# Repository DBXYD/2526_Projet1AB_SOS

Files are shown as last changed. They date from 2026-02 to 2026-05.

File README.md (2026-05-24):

# 2526_Projet1AB_SOS
## Introduction
### 1.1 Contexte et Problématique
Dans le cadre de la gestion logistique des laboratoires de l'ENSEA, le suivi précis et rigoureux des composants électroniques constitue un défi quotidien. Actuellement, l'inventaire repose sur un référencement manuel via un fichier Excel, et le stockage physique est réparti dans des boîtes de dimensions variables.
Ce mode de gestion présente plusieurs limites :

- Erreurs d'indexation : Risque élevé d'oublis ou de doubles saisies lors d'une mise à jour des stocks.
- Perte de traçabilité spatiale : Difficulté à localiser physiquement les boîtes suite à des déplacements ou réorganisations.
- Asynchronisme des données : Décalage temporel entre le mouvement réel d'un composant et sa mise à jour logicielle.

### 1.2 Objectifs du Projet SOS
Le projet SOS (Stock Organizer Scan) vise à concevoir un système embarqué de numérisation basé sur la technologie RFID (Radio Frequency Identification).
Chaque boîte de rangement se voit attribuer un tag RFID unique. Le dispositif SOS lit et écrit ces puces pour associer un contenant physique à ses données logistiques :
- Le MPN (Manufacturer Part Number) : référence exacte du constructeur
- SKU (Stock Keeping Unit) : code interne d'identification du stock
- LocalisationSalle précise au sein des différents tiroclasses de l'ENSEA
- Quantité exacte d'exemplaires restants

### 1.3 Solution mise en œuvre
Le projet s'articule autour de deux parties :

1) [Hardware](./Hardware) : Une carte électronique sur mesure intégrant une carte électronique sur mesure intégrant un microcontrôleur basse
consommation STM32L4, un lecteur RFID communiquant via bus SPI matériel, et une interface USB-C assurant à la fois l’alimentation et l’échange de données haut débit.

3) [Software](./Software) : Une interface utilisateur développée en Python, permettant aux techniciens d'interagir avec la base de données.

## 2. Analyse détaillée des blocs fonctionnels
Le schématique du système SOS (Stock Organizer Scan) est structuré de manière ri-
goureuse en blocs fonctionnels distincts.

### 2.1 Bloc Alimentation (Power Supply)



Ce bloc assure la conversion et la régulation de l'énergie nécessaire aux différents composants.

- Composants identifiés :
  - Régulateur LDO :  BU33SD5WG-TR (5 V → 3.3 V)
  - Condensateurs : C1 (1 μF) et C2 (1 μF)
  - Interrupteur : SW_SPDT (SW1)
  - LEDs indicatrices : D1 et D2 avec résistances associées R3 (3.4 kΩ) et R4 (1.6 kΩ)

- Justification des choix :
  - BU33SD5WG-TR : Ce régulateur (LDO) est particulièrement adapté pour abaisser le 5V issu de l’USB vers le rail 3.3 V. Son boîtier compact minimise l’empreinte au sol. De plus, sa capacité en courant ici est largement suffisante pour alimenter simultanément notre microcontrôleur STM32 et le lecteur RFID.

  - C1 et C2 (1 μF) : Placés en découplage direct sur l’entrée et la sortie du LDO conformément aux spécifications du constructeur. Ils stabilisent la tension ici.
  - SW1 (SW_SPDT) : Permet de couper l’alimentation de la carte sans avoir à débrancher physiquement le câble USB. Cela est plutôt intéressant d’un point de vue confort d’utilisation.

### 2.2 Bloc Port USB (USB-C)



L'interface USB-C gère le transfert de données et l'apport d'énergie principal.

- Composants identifiés :
  - Connecteur USB-C : J1 (Référence commerciale : 629722000214)
  - Protection ESD : U2 (USBLC6-2SC6)
  - Résistances de configuration : R1 (5.4 kΩ), R2 (5.1 kΩ) sur les lignes CC1/CC2
  - 
- Justification des choix :
  - Connecteur Molex USB-C : Nous avons opter ici pour USB-C et non un Micro-USB car
le premier est réversible et largement plus robustesse.
  - USBLC6-2SC6 : Réseau de diodes TVS bidirectionnel ultra-faible capacité dédié à la
protection des lignes D+ et D−. Cette protection est indispensable contre les décharges
électrostatiques (ESD) induites lorsque’un humaine manipule le connecteur USB manuellement.

### 2.3 Bloc STM32 (Microcontrôleur principal)



Le cœur logique du système repose sur le STM32L476RGTx (boîtier LQFP64) de STMicroelectronics. Composant central : STM32L476RGTx.

Ecosystème ENSEA : Il s’agit d’un composant sur lequel nous avons ulterieusrement eu a travaillé durant les séances de TD et TP surtout. SPI Matériel dispose de plusieurs bus SPI indépendants pour piloter à haute fréquence le lecteur RFID.

- Signaux notables :
  - SPI1_* → Liaison vers le lecteur RFID.
  - VCP_TX / VCP_RX → Interface UART pontée vers l’USB pour la communication avec le
script Python.
  - USB_DN / USB_DP → Lignes différentielles du bus USB physique.
  - SWDIO / SWCLK → Interface de programmation/débogage JTAG/SWD.
  - USR_LED_1 / USR_LED_2 → Indication d’état utilisateur (ex : scan réussi).
  - NRST / BOOT0 → Lignes de contrôle.
 
Remarque : Les condensateurs de découplage (C5 à C10, 100 nF) sont assignés individuellement à chaque broche d’alimentation VDD du STM32. Ils suppriment le bruit haute fréquence issu des commutations internes du coeur.

### 2.4 Bloc Lecteur RFID


Ce bloc gère l'acquisition des données des tags RFID attachés aux produits stockés.

- Interface SPI : Exploitation du bus à haute vitesse (jusqu’à 10 Mbit/s), réduisant la
latence lors de la lecture des identifiants.
- Compatibilité de tension : Fonctionnant sous 3.3 V, le composant fonctione directement
avec le STM32.
- Découplage local (C13,C14 - 1 μF) : Placés au plus près du circuit RFID pour pallier les
appels de courant violents générés par l’antenne lors de l’émission du champ magnétique
RF.

### 2.5 Bloc Connecteur SWD


Ce bloc offre un accès direct aux broches de débogage via une sonde externe de type ST-Link, pour le flashage et le débogage à chaud du microcontrôleur.

### 2.6 Boutons et signaux utilisateur





### 2.7 Trous de fixation (Mounting Pads)



Les quatre perçages H1 à H4 (MountingHole_Pad) garantissent la rigidité de l’intégration au sein d’un boîtier personnalisé.

## 3. Routage
Le passage du schéma théorique du [PCB](./PCB) permettant le tracé des pistes physiques impose le respect de contraintes géométriques et électromagnétiques strictes.



### 3.1 Réalisation Matérielle et Placements des blocs

La conception du circuit imprimé a abouti à une modélisation tridimensionnelle permettant de valider l’intégration mécanique des composants, l’accessibilité des connecteurs.

Le microcontrôleur STM32L476RGTx (boîtier LQFP64) occupe une position parfaitement centrale. Cette disposition permet une distribution homogène des pistes de signaux vers les différents périphériques, minimisant ainsi la longueur moyenne des pistes.

- Implantation des diffférents blocs :
  - Connecteur USB-C et Protection ESD : Placés au plus près du bord de la carte. L’alignement direct du circuit de protection TVS en entrée du connecteur garantit que les décharges électrostatiques sont immédiatement dérivées vers la masse avant de pouvoir se propager vers l’intérieur du circuit.
  - Connecteur d’extension RFID : Disposé sur la périphérie supérieure sous forme d’un connecteur femelle barrette, offrant une liaison mécanique et électrique stable pour le module MFRC522 tout en évitant les superpositions de composants.
  - Connecteur SWD (J2) : Isolé à droite afin de permettre un raccordement aisé de la sonde ST-Link lors des phases de flashage sans gêner l’accès au port USB principal.
  - Mounting Pads : la présence de quatre trous de fixation métallisés (Mounting Pads) répartis de manière symétrique aux quatre angles de la carte valide l’aptitude du prototype à être intégré de manière rigide au sein d’un boîtier de protection. L’espacement laissé libre autour de ces trous garantit le passage des têtes de vis sans risque d’écrasement ou de court-circuit sur les pistes environnantes.

## 4. Configuration des pins


Le microcontrôleur STM32L476RGTx (LQFP64) est configuré avec les affectations suivantes :



- Port A — SPI1 (NSS, SCK, MISO, MOSI), USB (DM, DP), VCP (TX, RX)
- Port B — RFID IRQ, boutons utilisateur (BTN_1, BTN_2), SWD, LEDs utilisateur
- Port C — OSC, LEDs, RFID RST
- Signaux de contrôle — NRST, BOOT0

## 5. Software
### 5.1 Firmware
La liaison entre le PC et le tag RFID à travers le PCB est gérée par du code en C, où on retrouve une séparation par composants. Le projet est construit de manière à pouvoir réutiliser des morceaux du code pour d’autres projets faisant intervenir des composants de celui-ci.\
Par la suite on détaillera seulement les fichiers contenant des fonctions écrites par nous, et non des fichiers générés par STM32CubeIDE lors de l'affectation des pins sur le .ioc (gpio, spi, usart,...).\

Dans le main.c se trouvent des appels aux fonctions d'initialisation et une boucle infinie où l'appel à test() de algo.c permet de tester des fonctionnalités en mode debuggeur.\
\
Le fichier rfid.c contient des fonctions ayant trait à la liaison SPI entre la STM32 et le lecteur RFID, et une structure permettant de définir les broches associées à un lecteur RFID. Cette dernière est initialisée grâce à la fonction RFID_init(hrfid, hspi, hspi_nss_port, hspi_nss_pin, rst_port, rst_pin). 

- void RFID_transmit(RFID_HandleTypeDef* hrfid, uint8_t* data, int size) transmet les données de data au tag et les y écrit;
- void RFID_receive(RFID_HandleTypeDef* hrfid, uint8_t* data, int size) lit les données du tag et les envoie au master en les stockant dans un buffer data.
- void RFID_transmit_receive(RFID_HandleTypeDef* hrfid, uint8_t* pTxData, uint8_t* pRxData, int size) fait les deux, l’un après l’autre.

Le fichier algo.c contient des fonctions rassemblant celles des autres fichiers, mettant ainsi bout à bout les différents éléments du PCB. Les fonctions read et write font alors intervenir le lecteur RFID et la liaison USART avec le PC. 

- void test() est utile pour la phase développement: elle aide à vérifier le fonctionnement de read(huart, hrfid, pdata, size) et write(huart, hrfid, pdata, size). On commence par lire le tag RFID, puis on y enregistre des données qu’on cherche enfin à retrouver en refaisant appel à read. 

- uint8_t SPI1_WriteRead(uint8_t data, SPI_HandleTypeDef hspi1) fait appel à RRFID_transmit_receive(hrfid, pTxData, pRxData, size). Elle est particulièrement utile dans les cas où ces deux actions doivent être effectuées l’une après l’autre. RFID_transmit_receive gère le délai de transmission. 

### 5.2 Interface Python
Pour assurer l’interface entre l’utilisateur et la carte électronique SOS, une application logicielle a été développée en Python qui était une condition nécéssaire dans notre projet. 
L’application s’appuie sur trois bibliothèques clés, assurant chacune un rôle pilier dans le traitement des données :
Le script Python s’appuie sur trois bibliothèques principales pour articuler ses différentes tâches. Elles sont structurées de la manière suivante :

- serial :
  - Rôle : Gestion de la couche de liaison série.
  - Utilité : Permet l’ouverture, la configuration et l’écoute du port COM virtuel (VCP) créé par le branchement USB-C du STM32. C’est elle qui intercepte le flux binaire.
    
- tkinter :
  - Rôle : Framework de construction d’Interface Homme-Machine (IHM).
  - Utilité : Bibliothèque standard de Python permettant de générer la fenêtre principale de l’application SOS, de positionner les boutons de contrôle et de mettre à jour dynamiquement les étiquettes de texte lors d’un scan.

- pandas :
  - Rôle : Manipulation et analyse de structures de données.
  - Utilité : Charge en mémoire le fichier tableur Excel faisant office de base de données d’inventaire de l’ENSEA. Elle permet d’effectuer des recherches indexées ultrarapides à partir d’un emplacement donné pour en extraire le MPN et le SKU.

Dans notre progremme Python, on retrouve les fonctions suivantes : 
- scan() :
  - Entrée : void
  - Rôle : Ouvre le canal de communication série USB-C avec le STM32.
  - Sortie : serial.Serial ou None : ser (instance de connexion)
- decode(data) :
  - Entrée : bytes : data
  - Rôle : Convertit les données en hexadécimal reçues en une listee de caractères utilisable.
  -Sortie : list[str,str,int,int,int] : location
- search_info(location) :
  - Entrée : list : location
  - Rôle : Requête de recherche au sein du fichier d’inventaire Excel 
  - Sortie : int : mpn, int : sku
- display_info(mpn, sku, location) :
  - Entrée : int : mpn, int : sku, list : location
  - Rôle : Met à jour dynamiquement l’interface graphique.
  - Sortie : NoneType : None
- read_data():
  - Entrée : void
  - Rôle : Suite à l'appui sur le bouton read, appelle les fonction scan, decode, search_info et display_info pour afficher SKU, MPN et localisation sur l'interface
  - Sortie : Nonetype : None
- write_loc():
  - Entrée : void
  - Rôle : demande à l'utilisateur la localisation à attribuer à la puce scannée 
  - Sortie : Nonetype : None
- display_value():
  - Entrée : void
  - Rôle : Suite à l'appui sur le bouton "done" (lorque l'utilisateur a entré la localisation et a terminé), convertit cette localisation en identifiant (locbytes) puis appelle la fonction assign_tag(loc_bytes)
  - Sortie : Nonetype : None
- assign_tag(loc_bytes):
  - Entrée : bytes loc_bytes
  - Rôle : Ouvre le canal de communication série USB-C avec le STM32 et envoie à la STM32 l'identifiant à attribuer à la puce.
  - Sortie : Nonetype : None
  
## 6. Question environnementale

A l'issue de notre projet nous avons finalement choisis la question : Votre projet recherche-t-il la rentabilité dans une perspective de viabilité financière ?

A cette question, nous y repondons *oui* et ce pour plusieurs raisons :
- **Gain de temps et d'organisation** : le système SOS permet aux techniciens de localiser instantanément les composants, réduisant les pertes de temps liées à la recherche manuelle en tiroir.
- **Économie d'argent important** : avec une actualisation automatique du système, nous pouvons éviter de recommander des composants déjà présents au sein de l'école.
- **Facilité de commande** : grâce au suivi précis des stocks (quantité, SKU, MPN), les réapprovisionnements sont déclenchés au bon moment, évitant les ruptures comme les sur-stocks inutiles.
- **"Le temps c'est de l'argent"** : chaque minute gagnée en gestion de stock est une minute réinvestie dans des tâches à plus forte valeur ajoutée.

En ce sens, le projet SOS s'inscrit pleinement dans une logique de rentabilité opérationnelle et de viabilité financière à long terme.

## Conslusion
Le projet SOS (Stock Organizer Scan) est, à ce stade, un projet en cours de développement dont on a malheuresement pas pu venir à bout. Cependant, nous avons pu faire une belle avancée : une carte électronique sur mesure intégrant un microcontrôleur STM32L4 et un lecteur RFID, couplée à une interface logicielle en Python, constitue une solution cohérente et pensée pour répondre à un besoin concret au sein de l'ENSEA.

Même inachevé, le projet démontre une réelle utilité : automatiser le suivi des composants électroniques, réduire les erreurs de gestion de stock et faciliter les commandes sont des apports directs pour les techniciens et les étudiants qui utilisent les tiroclasses au quotidien.

Ce projet nous a également permis de monter en compétences sur des technologies variées : conception PCB, communication SPI, développement logiciel et gestion de projet en équipe. Il constitue une base que d'autres promotions pourraient reprendre et faire évoluer vers un système pleinement opérationnel.

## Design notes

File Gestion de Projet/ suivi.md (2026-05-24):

# Evolution temporelle du projet
## Séance 1: Jeudi 5/02/26

Choix projet\
Prise en main github\
Nom projet\
Réflexions conception

## Séance 2: Jeudi 12/02/26
Attribution des taches de chacun\
Début de la liste d'achat des composants\
Fin du choix de la liste des composants\
Début de la réalisation du schéma

## Séance 3: Jeudi 19/02/26
Liste d'achat des composants\
Attributions des pins\
Création des empreintes\
Finition du schéma kicad\
Routage board

## Séance 4: Jeudi 12/03/26
Révision et vérification liste d'achat des composants\
Organisation de la documentation pour faciliter les références futures\
Travail sur l'architecture software:
- Identification pins à configurer
- Identification fonctions à coder

## Séance 5: Jeudi 19/03/26
Vérification PCB: changements certains composants\
Création nouveau board\
Travail sur l'architecture software: assignation des pins sur STM32CubeIDE et outline de leur configuration

## Séance 6: Jeudi 09/04/26
Test du lecteur RFID sur une STM32 avec code sur cube IDE\
Fin de l'attribution des empreintes\
Début du routage du PCB

## Séance 7: Jeudi 16/04
Complétion du routage\
Mise en format des diapositives de la présentation\
Mise en forme de la page d'explication de notre projet sur gitHub\
Prolongement des tests du lecteur RFID sur une STM32 avec code sur cube IDE\
Commande du PCB et fin des commandes des composants

## Séance 8: Jeudi 7/05
Présentation du routage\
Avancement des diapositives\
Avancement sur les codes\
Commande du PCB

## Séance 9: Jeudi 21/05
Dernière séance:\
Finalisation code interface\
Démonstration recherche composant et assignation nouveau tag\
Présentation du projet.

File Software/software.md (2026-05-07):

## Infos RFID
ID = emplacement sur RFID
MPN et SKU à partir du fichier excel

boîte et RFID indissociables + on part du principe qu'à une boîte=RFID correspond un emplacement: si on veut changer un composant de place on le change de boîte et on doit pouvoir modifier son emplacement sur le fichier excel

| format emplacement | salle | meuble | tiroir | colonne | ligne |
|--------:|-------  -|-----------|---------|-------|-------|
| max (entier/bits) taille | Patricia+D265/4 | tiro-class/4 | 9?/8 pour être sûrs | 12/4 | 8/4 |

## Fonctions à coder
### Fonctionnement PCB
rfid_init
rfid_reset
rfid_write
rfid_read
rfid_receive
rfid_transmit
rfid_transceive

Lecture infos:
- lecture tag RFID et transmission données à la STM
- décodage
- préparation données à transmettre en fonction de celles lues sur le tag
- transmission via USB au PC

Ecriture infos:
- transmission PC -> USB
- ...
- écriture sur le tag RFID

Enregistrement tag RFID (si nouveau par exemple) ...

### USB
AN 2.1.3 gestion Vusb après reset.

### Interface PC

## Pins à configurer
### Liste pins interconnectés
| Pin | Fonction | Composants connectés | Pins connectés | Source 1 | Commentaire 1 |Source 2 | Commentaire 2 |
|----:|---|---|---|---|---|---|---|
| PA5 | SPI1_SCK | STM32, RFID | SCLK: serial clock input | DS RFID | Schmitt-Trigger input | | |
| PA6 | SPI1_MISO | STM32, RFID | DIN: data input | DS RFID | Schmitt-Trigger input | RM STM| mode TI, CPOL= 0 ?, CPHA=1 |
| PA7 | SPI1_MOSI | STM32, RFID | DOUT: data output | DS RFID | open drain output with internal pull-up resistor | | |
| PA11 | USBDM | STM32, USB via protection diode | D- (A7, B7) | | | | |
| PA12 | USBDP | STM32, USB via protection diode | D+ (A6, B6) | | | | |
| PA13 | SWDIO | STM32, SWD conn | 4 | | | | |
| PA14 | SWCLK | STM32, SWD conn | 6 | | | | |
| PA15 | TDI | STM32, SWD conn | 10 | | | | |
| PB3 | TDO | STM32, SWD conn | 8 | | | | |
| NRST | NRST | STM32, SWD conn | 12 | | | | |
| PB4 | TRST | STM32, SWD conn | 3 | | | | |
| ? | VCP_IN | STM32, SWD conn | 13 | | | | |
| ? | VCP_OUT | STM32, SWD conn | 14 | | | | |

SPI1 in APB2 see 6.4.21 RM\
SPI -> 42 RM;
SPIx registers in 42.6 RM

### Liste pins autres
| Pin | Fonction | Composant connecté | Pins liés | Source 1 | Commentaire 1 |Source 2 | Commentaire 2 |
|----:|---|---|---|---|---|---|---|
| BOOT0 | BOOT0 | STM32 | | | | | |
| PH0 | OSC_IN | STM32 | | | | | |
| PH1 | OSC_OUT | STM32 | | | | | |

### Infos complémentaires
#### Lecture/Ecriture RFID
Incluant échange données avec PC.

Liste commandes dans DS_RFID 10:
- READ_TAG: recieved data at DOUT, to be decoded by uC
- WRITE_TAG(-N)

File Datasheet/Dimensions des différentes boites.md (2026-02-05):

# Dimension 

Boites d'un seul carré (5X5 cm)

Boites de deux carrés (5X11 cm)

Boites de quatres carrés (11X11 cm)

Boites de six carrés (11X17 cm)

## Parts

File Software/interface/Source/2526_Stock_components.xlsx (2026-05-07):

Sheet: components
 |  | References |  |  |  | Features |  |  |  |  |  | Link |  |  | Location
Category | Sub-Category | Manufacturer | MPN | Supplier | Supplier Ref | Quantity | Value | Type | Comment | SMD / THT | Footprint | Datasheet | Purchase | KiCad Lib | Room | Furniture | Drawer | Column | Raw
optoelectronic | LED | Dialight | 5988G10313F | Farnell | 3584522 | 60 | 20mA | LED RGB | R 2.4V, G 3.4V, B 3,4V | SMD | custom | https://www.mouser.fr/datasheet/2/109/C18481B-2944388.pdf | https://fr.farnell.com/dialight/5988g10313f/led-rgb-680mcd-1-5cd-380mcd-cms/dp/3584522 |  | D265 | Tiro-clas | 2 | 9 | 1
optoelectronic | IR | Vishay | TSOP75338TT | Farnell | 1779691 | 50 | 38kHz | IR Receiver Modules | 50° | SMD | custom | https://www.vishay.com/docs/82495/tsop753.pdf | https://fr.farnell.com/vishay/tsop75338tt/recepteur-ir-45m-0-12mw-m2-cms/dp/1779691 |  | D265 | Tiro-clas | 2 | 12 | 1
optoelectronic | LED | Wurth | 150060GS55040 |  |  | 100 | 20mA | Green | Vf = 3,2V | SMD | 0603 | https://www.we-online.com/components/products/datasheet/150060GS55040.pdf |  |  | D265 | Tiro-clas | 2 | 10 | 1
optoelectronic | LED | Wurth | 150060YS55040 |  |  | 100 | 20mA | Yellow | Vf = 2,0V | SMD | 0603 | https://www.we-online.com/components/products/datasheet/150060YS55040.pdf |  |  | D265 | Tiro-clas | 2 | 10 | 2
optoelectronic | LED | Wurth | 150060BS55040 |  |  | 100 | 20mA | Blue | Vf = 3,2V | SMD | 0603 | https://www.we-online.com/components/products/datasheet/150060BS55040.pdf |  |  | D265 | Tiro-clas | 2 | 10 | 3
optoelectronic | LED | Wurth | 150060RS55040 |  |  | 100 | 20mA | Red | Vf = 2,0V | SMD | 0603 | https://www.we-online.com/components/products/datasheet/150060RS55040.pdf |  |  | D265 | Tiro-clas | 2 | 10 | 4
optoelectronic | LED | Wurth | 150060AS55040 |  |  | 300 | 20mA | Amber | Vf = 2,0V | SMD | 0603 | https://www.we-online.com/components/products/datasheet/150060AS55040.pdf |  |  | D265 | Tiro-clas | 2 | 10 | 5
passiveComponents | resistors | TE Connectivity | RLP73K3AR11FTDF | Farnell | 2805295 | 30 | 0R11 | Shunt | 2W, 1% | SMD | 2512 | https://www.te.com/commerce/DocumentDelivery/DDEController?Action=srchrtrv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 | https://fr.farnell.com/te-connectivity/rlp73k3ar11ftdf/resis-mesure-courant-0r11-1-2w/dp/2805295 |  | D265 | Tiro-clas | 1 | 1 | 2
passiveComponents | resistors | TE Connectivity | RLP73K3AR16JTE | Farnell | 2805301 | 30 | 0R16 | Shunt | 2W, 5% | SMD | 2512 | https://www.te.com/commerce/DocumentDelivery/DDEController?Action=srchrtrv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 | https://fr.farnell.com/te-connectivity/rlp73k3ar16jte/resis-mesure-courant-0r16-5-2w/dp/2805301 |  | D265 | Tiro-clas | 1 | 1 | 3
passiveComponents | resistors | TE Connectivity | RLP73N3AR075JTE | Farnell | 2991966 | 30 | 0R075 | Shunt | 2W, 5% | SMD | 2512 | https://www.te.com/commerce/DocumentDelivery/DDEController?Action=srchrtrv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 | https://fr.farnell.com/cgs-te-connectivity/2-2176058-2/res-0r075-1-2w-2512-couche-epaisse/dp/2991966 |  | D265 | Tiro-clas | 1 | 1 | 1
passiveComponents | resistors | TE.com | HSC1004R7J | RS | 161-6160 | 5 | 4R7 | High power | 100W, 5% | - |  | https://www.te.com/commerce/DocumentDelivery/DDEController?Action=srchrtrv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 | https://fr.rs-online.com/web/p/resistances-a-montage-sur-chassis/1616160 |  | D265 | Tiro-clas | 1 | - | -
passiveComponents | resistors | Vishay | RCWE1210R300FKEA | Farnell | 1838677 | 10 | 0R3 | Shunt | 1W, 1% | SMD | 1210 | https://www.vishay.com/docs/20019/rcwe.pdf | https://fr.farnell.com/vishay/rcwe1210r300fkea/resistance-couche-epaisse-r3-1/dp/1838677 |  | D265 | Tiro-clas | 1 | 3 | 1
passiveComponents | inductors | Wurth | 744766001 |  |  | 8 | 100n | Wire inductor | 450 mA max | SMT | 4532 | https://www.we-online.com/components/products/datasheet/744766001.pdf |  |  | D265 | Tiro-clas | 1 | 5 | 1
passiveComponents | resistors | Wurth | 560050350011 |  |  | 50 | 0R2 | Shunt | 0,75W, 1% | SMD | 2010 | https://www.we-online.com/components/products/datasheet/560050350011.pdf |  |  | D265 | Tiro-clas | 1 | 2 | 1
passiveComponents | inductors | Wurth | 74438356220 |  |  | 3 | 22u | Power Inductor | 1,85A | SMT | 4020 | https://www.we-online.com/components/products/datasheet/74438356220.pdf |  |  | D265 | Tiro-clas | 1 | 5 | 2
passiveComponents | inductors | Wurth | 74404084220 |  |  | 40 | 22u | Power Inductor | 2,1A max | SMT | 8040 | https://www.we-online.com/components/products/datasheet/74404084220.pdf |  |  | D265 | Tiro-clas | 1 | 6 | 1
passiveComponents | inductors | Wurth | 74404086221 |  |  | 15 | 220u | Power Inductor | 0,95A max | SMT | 8065 | https://www.we-online.com/components/products/datasheet/74404086221.pdf |  |  | D265 | Tiro-clas | 1 | 6 | 2
passiveComponents | inductors | Wurth | 744066005 |  |  | 3 | 5u | Tiny Power Inductor | 5,3A max | SMT | 1035 | https://www.we-online.com/components/products/datasheet/744066005.pdf |  |  | D265 | Tiro-clas | 1 | 6 | 3
passiveComponents | inductors | Wurth | 7447709220 |  |  | 37 | 22u | Power Inductor | 6,5A | SMT | 1210 | https://www.we-online.com/components/products/datasheet/7447709220.pdf |  |  | D265 | Tiro-clas | 1 | 7 | 1
passiveComponents | inductors | Wurth | 784771220 |  |  | 6 | 22u | Power Inductor | 3,5A | SMT | 1260 | https://www.we-online.com/components/products/datasheet/744771122.pdf |  |  | D265 | Tiro-clas | 1 | 7 | 2
passiveComponents | capacitors | Wurth | 865060462010 |  |  | 48 | 1000u | Aluminum Electrolytic | 25V max | SMD | 12,5 x 14,0 | https://www.we-online.com/components/products/datasheet/865060462010.pdf |  |  | D265 | Tiro-clas | 1 | 10 | 1
passiveComponents | capacitors | Wurth | 865060445005 |  |  | 50 | 100u | Aluminum Electrolytic | 25V max | SMD | 6,3 x 7,7 | https://www.we-online.com/components/products/datasheet/865060445005.pdf |  |  | D265 | Tiro-clas | 1 | 9 | 5
passiveComponents | capacitors | Wurth | 865060440001 |  |  | 80 | 10u | Aluminum Electrolytic | 25V max | SMD | 4,0 x 5,5 | https://www.we-online.com/components/products/datasheet/865060440001.pdf |  |  | D265 | Tiro-clas | 1 | 9 | 2
passiveComponents | capacitors | Wurth | 865060640001 |  |  | 100 | 1u | Aluminum Electrolytic | 50V max | SMD | 4,0 x 5,5 | https://www.we-online.com/components/products/datasheet/865060640001.pdf |  |  | D265 | Tiro-clas | 1 | 11 | 1
passiveComponents | capacitors | Wurth | 865060463011 |  |  | 48 | 2200u | Aluminum Electrolytic | 25V max | SMD | 16,0 x 17,0 | https://www.we-online.com/components/products/datasheet/865060463011.pdf |  |  | D265 | Tiro-clas | 1 | 10 | 4
passiveComponents | capacitors | Wurth | 865080463017 |  |  | 10 | 2200u | Aluminum Electrolytic | 25V | SMD | 16,0x17,0 | https://www.we-online.com/components/products/datasheet/865080463017.pdf |  |  | D265 | Tiro-clas | 1 | 10 | 7
passiveComponents | capacitors | Wurth | 865060453007 |  |  | 48 | 220u | Aluminum Electrolytic | 25V max | SMD | 8,0 x 10,5 | https://www.we-online.com/components/products/datasheet/865060453007.pdf |  |  | D265 | Tiro-clas | 1 | 9 | 6
passiveComponents | capacitors | Wurth | 865060657012 |  |  | 16 | 220u | Aluminum Electrolytic | 50V max | SMD | 10,0 x 10,5 | https://www.we-online.com/components/products/datasheet/865060657012.pdf |  |  | D265 | Tiro-clas | 1 | 11 | 3
passiveComponents | inductors | Wurth | 7447709680 |  |  | 9 | 68u | Power Inductor | 3,2A | SMT | 1210 | https://www.we-online.com/components/products/datasheet/7447709680.pdf |  |  | D265 | Tiro-clas | 1 | 7 | 3
passiveComponents | inductors | Wurth | 744821120 |  |  | 4 | 20m | Common Mode Power Line Choke | 0,5A | THT | X5 | https://www.we-online.com/components/products/datasheet/744821120.pdf |  |  | D265 | Tiro-clas | 1 | 8 | 1
passiveComponents | capacitors | Wurth | 865060240001 |  |  | 8 | 22u | Aluminum Electrolytic | 10V max | SMD | 4,0 x 5,5 | https://www.we-online.com/components/products/datasheet/865060240001.pdf |  |  | D265 | Tiro-clas | 1 | 9 | 1
passiveComponents | capacitors | Wurth | 865060442002 |  |  | 30 | 22u | Aluminum Electrolytic | 25V max | SMD | 5,0 x 5,5 | https://www.we-online.com/components/products/datasheet/865060442002.pdf |  |  | D265 | Tiro-clas | 1 | 9 | 3
passiveComponents | capacitors | Wurth | 865060457009 |  |  | 38 | 470u | Aluminum Electrolytic | 25V max | SMD | 10,0 x 10,5 | https://www.we-online.com/components/products/datasheet/865060457009.pdf |  |  | D265 | Tiro-clas | 1 | 9 | 7
passiveComponents | capacitors | Wurth | 865060443004 |  |  | 30 | 47u | Aluminum Electrolytic | 25V max | SMD | 6,3 x 5,5 | https://www.we-online.com/components/products/datasheet/865060443004.pdf |  |  | D265 | Tiro-clas | 1 | 9 | 4
passiveComponents | capacitors | Wurth | 865060642004 |  |  | 40 | 4u7 | Aluminum Electrolytic | 50V max | SMD | 5,0 x 5,5 | https://www.we-online.com/components/products/datasheet/865060642004.pdf |  |  | D265 | Tiro-clas | 1 | 11 | 2
passiveComponents | capacitors | Wurth | 860010 |  |  | 1 | Kit | Aluminum Electrolytic | 16V max | THT | kit | https://www.we-online.com/en/components/products/download/inlay/860010 |  |  | Patricia
passiveComponents | capacitors | Wurth | 865061 |  |  | 1 | Kit | Aluminum Electrolytic | 1uF -> 2200uF, 25V -> 50V | SMD | kit | https://www.we-online.com/en/components/products/download/inlay/865061 |  |  | Patricia
passiveComponents | capacitors | Vishay | VJ0603HIFRQ1KITHT |  |  | 1 | Kit | MLCC | 1pF -> 47pF, 100V -> 200V | SMD | 0603 | https://www.vishay.com/docs/45259/vjhifreq-designkit.pdf |  |  | Patricia
passiveComponents | capacitors | Vishay | VJ0603HIFRQ2KITHT |  |  | 1 | Kit | MLCC | 56pF -> 270pF, 16V -> 50V | SMD | 0603 | https://www.vishay.com/docs/45259/vjhifreq-designkit.pdf |  |  | Patricia
passiveComponents | inductors | Wurth | 7447860139 |  |  | 100 | 39n | Multilayer SMD-inductors | 400mA | SMD | 0603 | https://www.we-online.com/components/products/datasheet/7447860139.pdf |  |  | D265 | Tiro-clas | 1 | 5 | 3
power | AC-DC_Converters | Multicomp Pro | MP-LD30-23B15R2 | Farnell | 3780527 | 4 | 15V | PSU | 2A, 30W max | THT | custom | https://www.farnell.com/datasheets/3550987.pdf | https://fr.farnell.com/multicomp-pro/mp-ld30-23b15r2/power-supply-ac-dc-15v-2a/dp/3780527 |  | D265 | Tiro-clas | 2 | - | -
power | AC-DC_Converters | Multicomp Pro | MP-LDE06-20B05 | Farnell | 3556397 | 4 | 5V | PSU | 1,2A, 6W max | THT | custom | https://www.farnell.com/datasheets/3155173.pdf | https://fr.farnell.com/multicomp-pro/mp-lde06-20b05/alimentation-ac-dc-5v-1-2a/dp/3556397 |  | D265 | Tiro-clas | 2 | - | -
power | AC-DC_Converters | TracoPower | TMLM 04253 | Farnell | 1772165 | 1 | 5V, 3.3V | PSU | 600mA max (5V), 150mA max (3,3V) | THT | custom | https://www.tracopower.com/sites/default/files/products/datasheets/tmlm_datasheet.pdf?t=1730163601 | https://fr.farnell.com/tracopower/tmlm-04253/alimentation-montage-pcb-4w-2/dp/1772165 |  | D265 | Tiro-clas | 2 | - | -
power | AC-DC_Converters | TracoPower | TMP 15148 | Farnell | 1672144 | 1 | 48V | PSU | 310mA, 15W max | THT | custom | https://www.tracopower.com/sites/default/files/products/datasheets/tmp_tmpm_datasheet.pdf?t=1730163601 | https://fr.farnell.com/traco-power/tmp-15148/convertisseur-ac-dc-48v-0-3a-15w/dp/1672144 |  | D265 | Tiro-clas | 2 | - | -
semiconductors | amplifier | Broadcom | HCPL-7800A-500E | RS | 174-4179 | 16 | 8V/V | Isolated Amplifier | 5,5V | SMD | Gull Wing 300 |  | https://fr.rs-online.com/web/p/amplificateurs-d-isolement/1744179 |  | D265 | Tiro-clas | 3 | 1 | 1
semiconductors | amplifier | Onsemi | NCS199A3RSQT2G | Farnell | 2981170 | 53 | G=200 | Current shunt monitors | 2,2V to 26V | SMD | SC-70 |  | https://fr.farnell.com/on-semiconductor/ncs199a3rsqt2g/ampli-musure-de-cour-40khz-40/dp/2981170 |  | D265 | Tiro-clas | 3 | 3 | 4
semiconductors | buffer | Texas Instrument | 74LVC2G241DCTRG4 | Mouser | 595-74LVC2G241DCTRG4 | 7 |  | Dual buffer 3-state outputs | 5V | SMD | SM-8 |  | https://www.mouser.fr/ProductDetail/Texas-Instruments/74LVC2G241DCTRE4?qs=pajgIaoyDUiznWLk8MWiIA%3D%3D |  | D265 | Tiro-clas | 3 | 3 | 3
embeddedSolutions | communicationRF |  | TXRX433 | GoTronic | 38176 | 8 | 433MHz RX/TX | Transceiver 433.92MHz | ASK | THT |  |  | https://www.gotronic.fr/art-kit-emetteur-recepteur-433-mhz-txrx433-36883.htm |  | D265 | Tiro-clas | 3 | 6 | 6
power | DC-DC_Converters | CUI Inc. | PQQ6W-Q24-S15-S | Mouser | 490-PQQ6W-Q24-S15-S | 18 | 15V | Isolated DC-DC | 6W max, 9V-36V in | THT | SIP-7 | https://www.mouser.fr/datasheet/2/670/pqq6w_s-2474782.pdf | https://www.mouser.fr/ProductDetail/CUI-Inc/PQQ6W-Q24-S15-S?qs=zW32dvEIR3vARH8AVKQkeg%3D%3D |  | D265 | Tiro-clas | 2 | 4 | 2
power | DC-DC_Converters | Multicomp Pro | MPRB2415S-6W | Farnell | 3652723 | 5 | 15V | Isolated DC-DC | 6W max, 9V-36V in | THT | SIP-7 | https://www.farnell.com/datasheets/3195174.pdf | https://fr.farnell.com/multicomp-pro/mprb2415s-6w/convertisseur-dc-dc-15v-0-4a/dp/3652723 |  | D265 | Tiro-clas | 2 | 4 | 3
power | DC-DC_Converters | Recom | R-78B5.0-2.0 | RS | 139-2959 | 0 | 5V | Step-Down | 2A max, 6,5V - 32V in | THT | SIP3 | https://g.recomcdn.com/media/Datasheet/pdf/.fldP_2rX/.t124a6889b0e40eeb9ac1/Datasheet-285/R-78B-2_0.pdf | https://fr.rs-online.com/web/p/regulateurs-a-decoupage/1392959 |  | D265 | Tiro-clas | 2 | 3 | 1
power | DC-DC_Converters | Wurth | 171013801 |  |  | 10 | 0,85V to 13V | Step-Down | 1A max, 3,5V - 38V in | SMD | custom | https://www.we-online.com/components/products/datasheet/171013801.pdf |  |  | D265 | Tiro-clas | 2 | 3 | 3
power | DC-DC_Converters | Wurth | 173950378 |  |  | 4 | 3,3V | Step-Down | 500mA max, 6V - 28V in | THT | Type F | https://www.we-online.com/components/products/datasheet/173950378.pdf |  |  | D265 | Tiro-clas | 2 | - | -
power | DC-DC_Converters | Wurth | 173950536 |  |  | 6 | 5V | Step-Down | 500mA max, 6,5V - 36V in | THT | Type F | https://www.we-online.com/components/products/datasheet/173950536.pdf |  |  | D265 | Tiro-clas | 2 | 3 | 2
power | DC-DC_Converters | Wurth | 17791063215 |  |  | 11 | 3,3V to 6V | Isolated DC-DC | 1W max, 8V to 42V | SMD | SIP-8 | https://www.we-online.com/components/products/datasheet/17791063215.pdf |  |  | D265 | Tiro-clas | 2 | 4 | 1
semiconductors | diodes | Diodes Inc. | 1N4148WS-7-F | Farnell | 1843678 | 20 | 1,25V | Low signal diode | 150mA max | SMD | SOD-323 | https://www.diodes.com/datasheet/download/1N4148WS.pdf | https://fr.farnell.com/diodes-inc/1n4148ws-7-f/diodess-commutateur75v0-2wsod323/dp/1843678 |  | D265 | Tiro-clas | 2 | 5 | 1
semiconductors | diodes | Littelfuse | DST10100S | Farnell | 4066566 | 35 | 10A | Schottky | 0,7V, 100V max | SMD | TO-227B | https://www.littelfuse.com/media?resourcetype=datasheets&itemid=912974f6-eef7-4845-b8b6-22945ea4a824 | https://fr.farnell.com/littelfuse/dst10100s/schottky-rectifier-100v-to-277b/dp/4066566 |  | D265 | Tiro-clas | 2 | 5 | 3
semiconductors | diodes | Onsemi | FSV340AF | Farnell | 2824885 | 18 | 3A | Schottky | 0,5V, 40V max | SMD | DO-214AD | https://www.onsemi.com/pdf/datasheet/fsv340af-d.pdf | https://fr.farnell.com/onsemi/fsv340af/diode-schottky-aec-q101-40v-do/dp/2824885 |  | D265 | Tiro-clas | 2 | 6 | 3
semiconductors | diodes | STMicroElectronic | STPS0520Z | Farnell | 1467545 | 3 | 500mA | Schottky | 20V max | SMD | SOD-123 | https://www.st.com/resource/en/datasheet/stps0520z.pdf | https://fr.farnell.com/stmicroelectronics/stps0520z/diode-schottky-2a-20v-cms-sod/dp/1467545 |  | D265 | Tiro-clas | 2 | 6 | 4
semiconductors | diodes | STMicroElectronic | USBLC6-2SC6 | RS | 624-7693 | 56 | 6V | TVS | USB protection | SMD | SOT-23 | https://www.st.com/resource/en/datasheet/usblc6-2.pdf | https://fr.rs-online.com/web/p/diodes-tvs/6247693 |  | D265 | Tiro-clas | 2 | 5 | 2
semiconductors | diodes | Vishay | SS2P5-M3/84A | Farnell | 1812486 | 18 | 2A | Schottky | 0,62V, 50V max | SMD | DO-220AA | https://www.vishay.com/docs/88943/ss2p5.pdf | https://fr.farnell.com/vishay/ss2p5-m3-84a/diode-rectifier-schottky-2a-50v/dp/1812486 |  | D265 | Tiro-clas | 2 | 6 | 2
semiconductors | diodes | Vishay | VS-15TQ060S-M3 | Farnell | 2909608 | 35 | 15A | Schottky | 0,56V , 60V max | SMD | TO-263AB | https://www.vishay.com/docs/94927/vs-15tq060s-m3.pdf | https://fr.farnell.com/vishay/vs-15tq060s-m3/diode-schottky-simple-60v-to263ab/dp/2909608 |  | D265 | Tiro-clas | 2 | 6 | 1
semiconductors | gateDriver | Broadcom | HCPL-315J_500E | RS | 174-4163 | 7 | 0,5A | Dual Channel gate Driver optocoupler |  | SMD | SO-16 |  | https://fr.rs-online.com/web/p/optocoupleurs/1744163 |  | D265 | Tiro-clas | 3 | 1 | 2
semiconductors | gpioExpander | NXP | PCF8574TS/3,118 | RS | 219-4650 | 9 | 8 channels | I2C 8-channel gpio Expander | 2,5V - 6V | SMD | SSOP20 |  | https://fr.rs-online.com/web/p/expandeurs-e-s/2194650 |  | D265 | Tiro-clas | 3 | 3 | 1
semiconductors | gpioExpander | Microchip | MCP23017-E/SO | RS | 403-816 | 8 | 16 channels | I2C 16-channel gpio Expander | 1V8 - 5V5 | SMD | SOIC-28 |  | https://fr.rs-online.com/web/p/expandeurs-e-s/0403816?gb=s&searchId=5777323f-195c-44f1-b92f-cb4dbfb01835 |  | D265 | Tiro-clas | 3 | 4 | 3
semiconductors | integratedCircuits | Microchip | MCP2120-I/SL | Farnell | 1084305 | 2 | 312,5kBaud | IrDA Encode/Decode | UART to IR | SMD | SOIC-14 | https://ww1.microchip.com/downloads/aemDocuments/documents/APID/ProductDocuments/DataSheets/21618b.pdf | https://fr.farnell.com/microchip/mcp2120-i-sl/controleur-irda-cms/dp/1084305 |  | D265 | Tiro-clas | 2 | - | -
semiconductors | integratedCircuits | Texas Instrument | LM3404MA/NOPB | Mouser | 926-LM3404MA/NOPB | 8 | 1A | Led driver | 6V to 42V in | SMD | SOIC-8 | https://www.ti.com/lit/ds/symlink/lm3404.pdf?ts=1730061548853 |  |  | D265 | Tiro-clas | 2 | - | -
semiconductors | ledDriver | NXP | CA9685PW,118 | Farnell | 1854074 | 9 | 16 channels | Driver LED, Bus I2C, 12 bits | 2,3 - 5,5V/25mA | SMD | TSSOP-28 |  | https://fr.farnell.com/nxp/pca9685pw-118/driver-de-led-rgba-28-tssop/dp/1854074 |  | D265 | Tiro-clas | 3 | 4 | 4
semiconductors | motorDriver | Trinamic | TMC2225-SA-T | Farnell | 3690353 | 51 | stepper driver | Stepper, 1 output, PWM/UART input | 4,75V - 36V, 2A max | SMD | HTSSOP-28 |  | https://fr.farnell.com/trinamic/tmc2225-sa-t/driver-de-moteur-2a-40-a-125-c/dp/3690353 |  | D265 | Tiro-clas | 3 | 5 | 3
semiconductors | motorDriver | Trinamic | TMC2226-SAT-T | Farnell | 3439216 | 6 | stepper driver | Stepper, 1 output, PWM/UART input | 4,75V - 29V, 2.8A max | SMD | HTSSOP-28 |  | https://fr.farnell.com/trinamic/tmc2226-sa-t/driver-de-moteur-40-a-125-c/dp/3439216 |  | D265 | Tiro-clas | 3 | 5 | 2
semiconductors | motorDriver | Trinamic | TMC2590-TA | Farnell | 3237586 | 17 | stepper driver | Stepper driver for two-phase bipolar motors with external MOSFETs, PWM/SPI input | 5V | SMD | TQFP-EP |  | https://fr.farnell.com/trinamic/tmc2590-ta/driver-de-moteur-40-a-125-c/dp/3237586 |  | D265 | Tiro-clas | 3 | 5 | 1
semiconductors | powerManagementICs | Analog Device | LT1076CR#PBF | Mouser | 584-LT1076CR#PBF | 7 | 2,5V to 50V | Step-Down | 2,6A max | SMD | custom | https://www.analog.com/media/en/technical-documentation/data-sheets/1074fds.pdf | https://www.mouser.fr/ProductDetail/Analog-Devices/LT1076CRPBF?qs=ytflclh7QUUzWtSF1iWaww%3D%3D |  | D265 | Tiro-clas | 2 | 2 | 1
semiconductors | powerManagementICs | Analog Device | MAX5033DUSA+ | Mouser | 700-MAX5033DUSA | 10 | 1,25V to 13,2V |  | 500mA max, 7,5V to 76V in | SMD | SOIC-8 | https://www.analog.com/media/en/technical-documentation/data-sheets/MAX5033.pdf | https://www.mouser.fr/ProductDetail/Analog-Devices-Maxim-Integrated/MAX5033DUSA%2b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 |  | D265 | Tiro-clas | 2 | - | -
semiconductors | powerManagementICs | Diodes Inc. | AP1509-50SG-13 | RS | 751-2923 | 10 | 5V | Step-Down | 2A max, 22V in, 150kHz | SMD | SOP-8L | https://www.diodes.com/datasheet/download/AP1509.pdf | https://fr.rs-online.com/web/p/convertisseurs-buck/7512923 |  | D265 | Tiro-clas | 2 | 2 | 2
semiconductors | powerManagementICs | Diodes Inc. | AZ1117CH2-3.3TRG1 | Farnell | 3483072 | 45 | 3,3V | LDO | 0,8A, max 18V | SMD | SOT-223 | https://www.diodes.com/datasheet/download/AZ1117C.pdf | https://fr.farnell.com/diodes-inc/az1117ch2-3-3trg1/ldo-fixe-3-3v-0-8a-20-a-125-c/dp/3483072 |  | D265 | Tiro-clas | 2 | 2 | 5
semiconductors | powerManagementICs | Diodes Inc. | AZ1117CH-3.3TRG1 | Farnell | 3483073 | 137 | 3,3V | LDO | 0,8A, max 18V | SMD | SOT-223 | https://www.diodes.com/datasheet/download/AZ1117C.pdf | https://fr.farnell.com/diodes-inc/az1117ch-3-3trg1/ldo-fixe-3-3v-0-8a-20-a-125-c/dp/3483073 |  | D265 | Tiro-clas | 2 | - | -
semiconductors | powerManagementICs | Diodes Inc. | AZ1117H-3.3TRE1 | RS | 921-0701 | 45 | 3,3V | LDO | 1A max, max 20V | SMD | SOT-223 | https://www.diodes.com/datasheet/download/AZ1117.pdf | https://fr.rs-online.com/web/p/regulateurs-de-tension/9210701 |  | D265 | Tiro-clas | 2 | 2 | 4
semiconductors | powerManagementICs | Microchip | MIC3172YM | Farnell | 2510055 | 24 | 3V-40V | Step-up | 1,25A | SMD | SOIC-8 | https://ww1.microchip.com/downloads/aemDocuments/documents/OTH/ProductDocuments/DataSheets/MIC2172-3172-100kHz-1.25A-Switching-Regulators-DS20006208A.pdf | https://fr.farnell.com/microchip/mic3172ym/ic-switching-reg-1-25a-100khz/dp/2510055 |  | D265 | Tiro-clas | 2 | 2 | 3
semiconductors | powerManagementICs | Microchip | MIC5219-3.3YMM | Farnell | 2510255 | 17 | 3,3V | LDO | 500mA, max 12V | SMD | SOP-8 | https://ww1.microchip.com/downloads/aemDocuments/documents/OTH/ProductDocuments/DataSheets/MIC5219-500mA-Peak-Output-LDO-Regulator-DS20006021A.pdf | https://fr.farnell.com/microchip/mic5219-3-3ymm/ldo-reg-12vin-0-5a-3-3v-1-8msop/dp/2510255 |  | D265 | Tiro-clas | 2 | 1 | 4
semiconductors | powerManagementICs | Microchip | MIC5317-3.3YM5-TR | Farnell | 2920683 | 8 | 3,3V | LDO | 150mA, max 6V | SMD | SOT-23 | https://ww1.microchip.com/downloads/aemDocuments/documents/OTH/ProductDocuments/DataSheets/MIC5317-High-Performance-Single-150mA-LDO-DS20006195B.pdf | https://fr.farnell.com/microchip/mic5317-3-3ym5-tr/ldo-fixe-3-3v-015a-40-a-125-c/dp/2920683 |  | D265 | Tiro-clas | 2 | - | -
sensors | current | LEM | GO 10-SME/SP3 | Farnell | 3796461 | 3 | 10A | Galvanic isolation current sensor | 3,3V | SMD | SOIC-8 |  | https://fr.farnell.com/lem/go-10-sme-sp3/capteur-courant-300khz-soic-8/dp/3796461 |  | D265 | Tiro-clas | 3 | 1 | 3
semiconductors | powerManagementICs | Rohm | BU18SD2MG-MTR | Farnell | 2546639 | 50 | 1,8V | LDO | 200mA, max 6V in | SMD | SSOP-5 | https://fscdn.rohm.com/en/products/databook/datasheet/ic/power/linear_regulator/buxxsd2mg-m-e.pdf | https://fr.farnell.com/rohm/bu18sd2mg-mtr/ldo-fixe-aec-q100-1-8v-0-2a-ssop/dp/2546639 |  | D265 | Tiro-clas | 2 | 1 | 2
semiconductors | powerManagementICs | Rohm | BU33SD5WG-TR | Farnell | 3011248 | 45 | 3,3V | LDO | 500mA, max 6V in | SMD | SSOP-5 | https://fscdn.rohm.com/en/products/databook/datasheet/ic/power/linear_regulator/buxxsd5wg-e.pdf | https://fr.farnell.com/rohm/bu33sd5wg-tr/ldo-fixe-3-3v-0-5a-40-a-105-c/dp/3011248 |  | D265 | Tiro-clas | 2 | 1 | 1
passiveComponents | quartz | Ecliptek | EC2620TS-25.000M TR | Farnell | 3572937 | 9 | 25MHz | Quartz | 15pF | SMD | 7mm x 5mm |  | https://fr.farnell.com/ecliptek/ec2620ts-25-000m-tr/oscillateur-25mhz-lvcmos-7mm-x/dp/3572937 |  | D265 | Tiro-clas | 3 | 2 | 4
passiveComponents | quartz | Murata Electronics | XRCGB27M120F3M00R0 | Mouser | 81-XRCGB27M120F3M0R0 | 7 | 27,12MHz | Quartz | 6pF | SMD | 2mm x 1,6mm |  | https://www.mouser.fr/ProductDetail/Murata-Electronics/XRCGB27M120F3M00R0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 |  | D265 | Tiro-clas | 3 | 2 | 3
passiveComponents | quartz | Abracon | ABLS-16.000MHZ-20-B-3-H-T | Farnell | 3228387 | 39 | 16Mhz | Quartz |  | SMD | 11,5mm x 4,7mm |  | https://fr.farnell.com/abracon/abls-16-000mhz-20-b-3-h-t/quartz-16mhz-20pf-cms-hc-49us/dp/3228387 |  | D265 | Tiro-clas | 3 | 2 | 2
passiveComponents | quartz | Abracon | ABLS-7.3728MHZ-20-B-3-H-T | Farnell | 3228448 | 3 | 7,3728MHz | Quartz | 20pF | SMD | 11,5mm x 4,7mm |  | https://fr.farnell.com/abracon/abls-7-3728mhz-20-b-3-h-t/quartz-7-3728mhz-20pf-cms-hc-49us/dp/3228448 |  | D265 | Tiro-clas | 3 | 2 | 1
semiconductors | powerManagementICs | STMicroElectronic | L78M05CDT-TR | Farnell | 2382524 | 10 | 5V | LDO | 500mA, 10V-35V | SMD | TO-252-3 | https://www.st.com/resource/en/datasheet/l78m.pdf | https://fr.farnell.com/stmicroelectronics/l78m05cdt-tr/regulateur-de-tension-5v-0-5a/dp/2382524 |  | D265 | Tiro-clas | 2 | 1 | 3
semiconductors | powerManagementICs | Power Integrations | INN4073C-H183-TL | RS | 228-6331 | 4 | 1,7A | Flyback | 60W | SMD | custom |  | https://fr.rs-online.com/web/p/convertisseurs-ac-dc/2286331 |  | D265 | Tiro-clas | 3 | 1 | 4
optoelectronic | phototransistor | Broadcom | HCPL-817-300E | Farnell | 1244557 | 5 |  | Optocoupler phototransistor | 1,2V, 20mA | SMD | Gull Wing |  | https://fr.farnell.com/broadcom-limited/hcpl-817-300e/optocoupleur-tr-o-p-cms/dp/1244557 |  | D265 | Tiro-clas | 3 | 3 | 2
semiconductors | powerManagementICs | Power Integrations | CPZ1061M | RS | 228-6322P | 4 |  | Flyback | 75W | SMD | custom |  | https://fr.rs-online.com/web/p/convertisseurs-ac-dc/2286322P |  | D265 | Tiro-clas | 3 | 1 | 4
semiconductors | transceiverEth | Microchip | LAN8742A-CZ-TR | Farnell | 2857750 | 9 | 100Mbits | Transceiver Ethernet PHY, IEEE 802.3, IEEE 802.3u |  | SMD | SQFN |  | https://fr.farnell.com/microchip/lan8742a-cz-tr/transceiver-ethernet-10-100-mbps/dp/2857750 |  | D265 | Tiro-clas | 3 | 5 | 4
semiconductors | transceiverRF | Nordic Semiconductor | NRF24L01P-R7 | Farnell | 2842317 | 10 | Transceiver RF | 2.4GHz à 2.525GHz, GFSK | 2Mbps | SMD | QFN-20 |  | https://fr.farnell.com/nordic-semiconductor/nrf24l01p-r7/transceiver-rf-2mbps-2-525ghz/dp/2842317 |  | D265 | Tiro-clas | 3 | 4 | 1
sensors | IMU | STMicroElectronic | LSM6DSMTR | Farnell | 2664522 | 2 | accelerometer, gyroscope | IMU, ±16g | 1V7 - 3V6 | SMD | LGA-14L |  | https://fr.farnell.com/stmicroelectronics/lsm6dsmtr/mems-accelero-gyroscope-3d-lga/dp/2664522 |  | D265 | Tiro-clas | 3 | 4 | 2
semiconductors | transistors | Vishay | SQJ504EP-T1_GE3 | Farnell | 2886991 | 37 | 30A | Dual Mosfet (N+P) | 40V max | SMD | PowerPak SO | https://www.vishay.com/docs/76029/sqj504ep.pdf | https://fr.farnell.com/vishay/sqj504ep-t1-ge3/mosfet-aec-q101-canal-n-p-40v/dp/2886991 |  | D265 | Tiro-clas | 2 | 7 | 1
semiconductors | transistors | Rohm | RE1C002UNTCL | Farnell | 2965337 | 20 | 200mA | Mosfet N | 20V max | SMD | SOT-416FL | https://fscdn.rohm.com/en/products/databook/datasheet/discrete/transistor/mosfet/re1c002untcl-e.pdf | https://fr.farnell.com/rohm/re1c002untcl/mosfet-canal-n-20v-0-2a-150-c/dp/2965337 |  | D265 | Tiro-clas | 2 | 7 | 2
semiconductors | transistors | Nexperia | BUK9637-100E,118 | Farnell | 2254193 | 19 | 31A | Mosfet N | 100V max | SMD | TO-263 | https://assets.nexperia.com/documents/data-sheet/BUK9637-100E.pdf | https://fr.farnell.com/nexperia/buk9637-100e-118/mosfet-n-ch-100v-31a-d2pak/dp/2254193 |  | D265 | Tiro-clas | 2 | 7 | 3
semiconductors | transistors | Infineon | IRF540NPBF | RS | 914-8154 | 50 | 33A | Mosfet N | 33A max | THT | TO-220 | https://www.infineon.com/dgdl/Infineon-IRF540N-DataSheet-v01_01-EN.pdf?fileId=5546d462533600a4015355e39f0d19a1 | https://fr.rs-online.com/web/p/transistors-mosfet/9148154 |  | D265 | Tiro-clas | 2 | 8 | 1
semiconductors | transistors | Vishay | IRF510SPBF | Mouser | 844-IRF510SPBF | 20 | 5,6A | Mosfet N | 100V max | SMD | TO-263 | https://www.vishay.com/docs/91016/sihf510s.pdf | https://www.mouser.fr/ProductDetail/Vishay-Semiconductors/IRF510SPBF?qs=iXwvDCb7I7jeKqUeAvChjw%3D%3D |  | D265 | Tiro-clas | 2 | 8 | 3
semiconductors | transistors | Vishay | SQ2310ES-T1_BE3 | RS | 787-9443 | 22 | 6A | Mosfet N | 20V max | SMD | SOT-23 | https://www.vishay.com/docs/67036/sq2310es.pdf | https://fr.rs-online.com/web/p/transistors-mosfet/7879443 |  | D265 | Tiro-clas | 2 | 8 | 4
 |  |  | BMP085 |  |  | 1 |  |  |  |  |  |  |  |  | D265 | Tiro-clas | 3 | 6 | 5
 |  |  | IDUINO HC-05 |  |  | 3 |  |  |  |  |  |  |  |  | D265 | Tiro-clas | 3 | 6 | 3
 |  |  | NRF24L05 |  |  | 6 |  |  |  |  |  |  |  |  | D265 | Tiro-clas | 3 | 6 | 2
 |  |  | module LORA 113060006 |  |  | 4 |  |  |  |  |  |  |  |  | D265 | Tiro-clas | 3 | 6 | 1
 |  |  | adafruit QT PY C3 |  |  | 1 |  |  |  |  |  |  |  |  | D265 | Tiro-clas | 3 | 7 | 6
 |  |  | IMU 10DOF |  |  | 2 |  |  |  |  |  |  |  |  | D265 | Tiro-clas | 3 | 7 | 5
 |  |  | MAX3097ECSE+ |  |  | 5 |  |  |  |  |  |  |  |  | D265 | Tiro-clas | 3 | 7 | 4
 |  |  | CY7C64225-28PVXCT |  |  | 5 |  |  |  |  |  |  |  |  | D265 | Tiro-clas | 3 | 7 | 3
 |  |  | CY7C64225-28PVXC |  |  | 9 |  |  |  |  |  |  |  |  | D265 | Tiro-clas | 3 | 7 | 2
 |  |  | SBC-TTL |  |  | 3 |  |  |  |  |  |  |  |  | D265 | Tiro-clas | 3 | 7 | 1
 |  |  | TCN75AVOA |  |  | 12 |  |  |  |  |  |  |  |  | D265 | Tiro-clas | 3 | 6 | 4
passiveComponents | capacitors | Kemet | CER-ENG-KIT-30 | RS | 867-5444 | 1 | Kit | MLCC | 10pF -> 22uF, 6,3V -> 100V | SMD | 0805 | https://content.kemet.com/datasheets/CER_ENG_KIT_30.pdf | https://fr.rs-online.com/web/p/kits-de-condensateurs/8675444 |  | Patricia
passiveComponents | capacitors | Wurth | 885080 |  |  | 1 | Kit | MLCC | 1nF -> 22uF, 6,3V -> 50V | SMD | 1206, 1210, 1812 | https://www.we-online.com/en/components/products/download/inlay/885080 |  |  | Patricia
passiveComponents | capacitors | Wurth | 885060 |  |  | 1 | Kit | MLCC | 1pF -> 10uF, 6,3V -> 50V | SMD | 0603 | https://www.we-online.com/en/components/products/download/inlay/885060 |  |  | Patricia
passiveComponents | capacitors | Vishay | VJ0805HIFRQ2KITHT |  |  | 1 | Kit | MLCC | 100pF -> 1nF, 16V -> 100V | SMD | 0805 | https://www.vishay.com/docs/45259/vjhifreq-designkit.pdf |  |  | Patricia
passiveComponents | capacitors | Wurth | 885070 |  |  | 1 | Kit | MLCC | 1pF -> 47uF, 6,3V -> 50V | SMD | 0805 | https://www.we-online.com/en/components/products/download/inlay/885070 |  |  | Patricia
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

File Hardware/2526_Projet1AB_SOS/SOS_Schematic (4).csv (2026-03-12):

Reference | Qty | Value | DNP | Exclude from BOM | Exclude from Board | Footprint | Datasheet
C1,C2,C3,C7,C10,C11,C14,C15 | 8 | 100n |  |  |  | Capacitor_SMD:C_0603_1608Metric_Pad1.08x0.95mm_HandSolder | ~
C4 | 1 | 10u |  |  |  | Capacitor_SMD:C_0603_1608Metric_Pad1.08x0.95mm_HandSolder | ~
C5 | 1 | 1,5n |  |  |  | Capacitor_SMD:C_0603_1608Metric_Pad1.08x0.95mm_HandSolder | ~
C6,C8 | 2 | 22p |  |  |  | Capacitor_SMD:C_0603_1608Metric_Pad1.08x0.95mm_HandSolder | ~
C9 | 1 | 4,7u |  |  |  | Capacitor_SMD:C_0603_1608Metric_Pad1.08x0.95mm_HandSolder | ~
C12 | 1 | 10n |  |  |  | Capacitor_SMD:C_0603_1608Metric_Pad1.08x0.95mm_HandSolder | ~
C13,C17,C18,C20 | 4 | 1u |  |  |  | Capacitor_SMD:C_0603_1608Metric_Pad1.08x0.95mm_HandSolder | ~
C16,C19 | 2 | 20p |  |  |  | Capacitor_SMD:C_0603_1608Metric_Pad1.08x0.95mm_HandSolder | ~
H1,H2,H3,H4 | 4 | MountingHole_Pad |  |  |  | MountingHole:MountingHole_3.2mm_M3_DIN965_Pad | ~
J1 | 1 | USB_B_Mini |  |  |  | Connector_USB:USB_Mini-B_Tensility_54-00023_Vertical | ~
J2 | 1 | Conn_02x10_Odd_Even |  |  |  | Connector_PinHeader_1.27mm:PinHeader_2x10_P1.27mm_Vertical_SMD | ~
J3 | 1 | Conn_01x02 |  |  |  | Connector_JST:JST_XH_B2B-XH-A_1x02_P2.50mm_Vertical | ~
L1 | 1 | 1/2 uH |  |  |  | Inductor_SMD:L_0805_2012Metric_Pad1.05x1.20mm_HandSolder | ~
L2 | 1 | L_Small |  |  |  | Inductor_SMD:L_0805_2012Metric_Pad1.05x1.20mm_HandSolder | ~
R1 | 1 | 2,2k |  |  |  | Resistor_SMD:R_0805_2012Metric_Pad1.20x1.40mm_HandSolder | ~
R2,R4,R5,R6 | 4 | 10k |  |  |  | Resistor_SMD:R_0805_2012Metric_Pad1.20x1.40mm_HandSolder | ~
R3 | 1 | 100K |  |  |  | Resistor_SMD:R_0805_2012Metric_Pad1.20x1.40mm_HandSolder | ~
R7 | 1 | 390 |  |  |  | Resistor_SMD:R_0805_2012Metric_Pad1.20x1.40mm_HandSolder | ~
SW1 | 1 | SW_SPDT |  |  |  | Button_Switch_THT:SW_Push_1P2T_Vertical_E-Switch_800UDP8P1A1M6 | ~
U1 | 1 | BU33SD5WG-TR |  |  |  | Package_TO_SOT_SMD:SOT-23-5 | http://ww1.microchip.com/downloads/en/DeviceDoc/22053C.pdf
U2 | 1 | STM32L476RGTx |  |  |  | Package_QFP:LQFP-64_10x10mm_P0.5mm | https://www.st.com/resource/en/datasheet/stm32l476rg.pdf
U3 | 1 | HTRC11001T |  |  |  | Package_SO:SOIC-14_3.9x8.7mm_P1.27mm | https://www.nxp.com/docs/en/data-sheet/037031.pdf
Y1 | 1 | 13,56MHz |  |  |  | Crystal:Crystal_DS10_D1.0mm_L4.3mm_Vertical | ~
Y2 | 1 | 8MHz |  |  |  | Crystal:Crystal_DS10_D1.0mm_L4.3mm_Vertical | ~

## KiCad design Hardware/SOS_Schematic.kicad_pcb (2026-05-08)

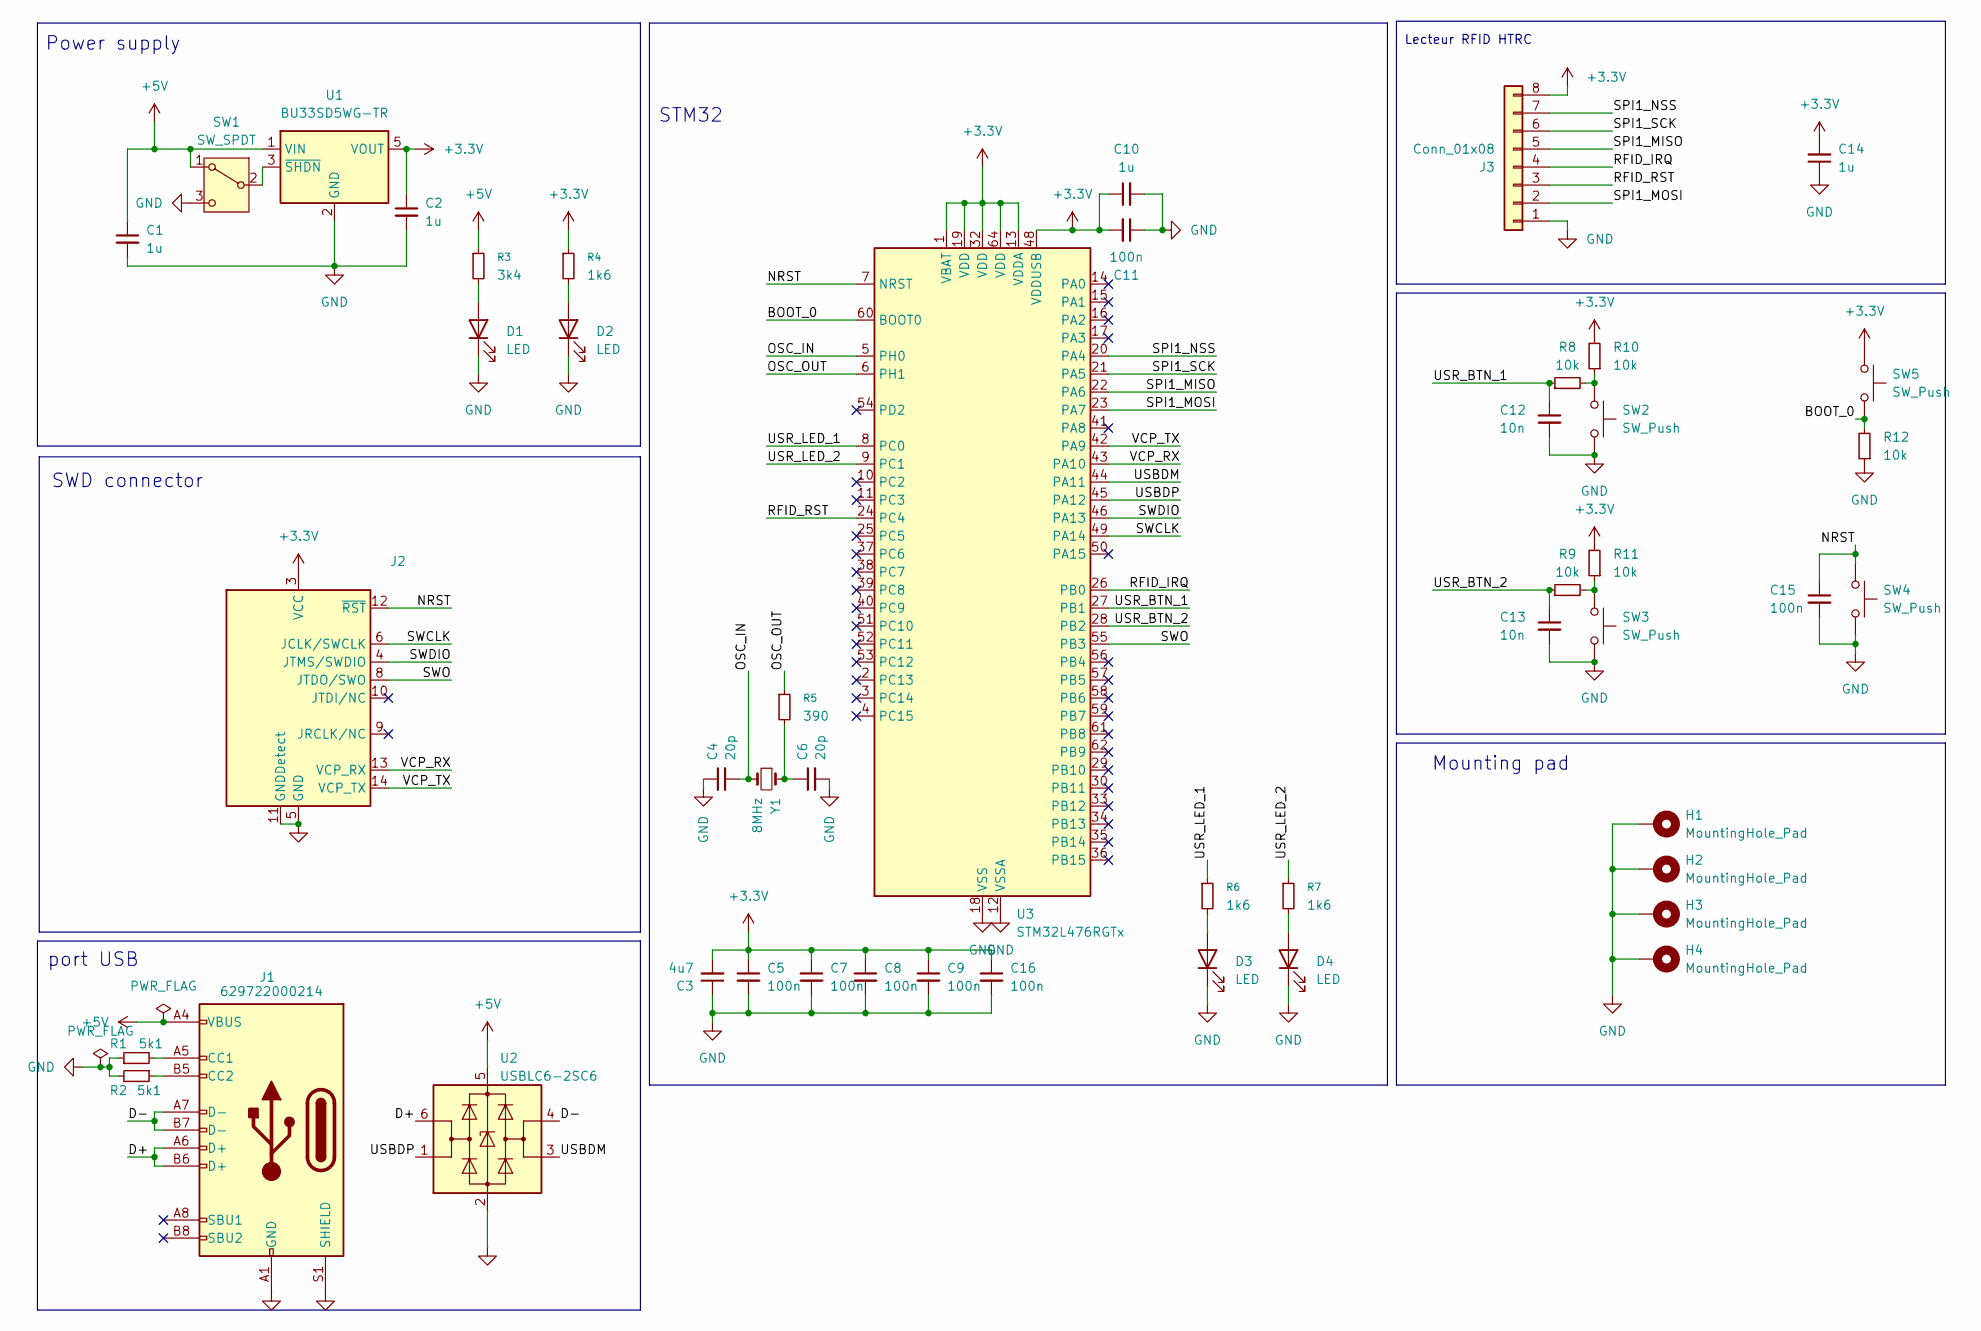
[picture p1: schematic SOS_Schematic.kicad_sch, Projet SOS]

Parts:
C1, C2, C10, C14: 1u; C_0402_1005Metric
C3: 4u7; C_0603_1608Metric
C4, C6: 20p; C_0402_1005Metric
C5, C7, C8, C9, C11, C15, C16: 100n; C_0402_1005Metric
C12, C13: 10n; C_0402_1005Metric
D1, D2, D3, D4: LED; LED_0603_1608Metric; MPN 150060RS55040
H1, H2, H3, H4: MountingHole_Pad; MountingHole_3.2mm_M3_DIN965_Pad
J1: 629722000214; USB_C_Receptacle_HRO_TYPE-C-31-M-12; MPN WE 629722000214
J2: PinHeader_2x07_P1.27mm_Vertical_SMD
J3: Conn_01x08; PinSocket_1x08_P2.54mm_Vertical
R1, R2: 5k1; R_0402_1005Metric
R3: 3k4; R_0402_1005Metric
R4, R6, R7: 1k6; R_0402_1005Metric
R5: 390; R_0402_1005Metric
R8, R9, R10, R11, R12: 10k; R_0402_1005Metric
SW1: SW_SPDT; SW_SPDT_CK_JS102011SAQN
SW2, SW3, SW4, SW5: SW_Push; SW_SPST_CK_KMS2xxG; MPN KSS221GLFS
U1: BU33SD5WG-TR; SOT-23-5
U2: USBLC6-2SC6; SOT-23-6; MPN USBLC6-2SC6
U3: STM32L476RGTx; LQFP-64_10x10mm_P0.5mm
Y1: 8MHz; Crystal_SMD_Abracon_ABM7-2Pin_6.0x3.5mm

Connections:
+3.3V: C2.1, C3.2, C5.1, C7.1, C8.1, C9.1, C10.1, C11.2, C14.2, C16.1, J2.3 (VCC), J3.8, R4.1, R10.2, R11.2, SW5.1, U1.5 (VOUT), U3.1 (VBAT), U3.13 (VDDA), U3.19 (VDD), U3.32 (VDD), U3.48 (VDDUSB), U3.64 (VDD)
+5V: C1.1, J1.A4 (VBUS), J1.A9 (VBUS), J1.B4 (VBUS), J1.B9 (VBUS), R3.1, SW1.1 (A), U1.1 (VIN), U2.5 (VBUS)
/BOOT_0: R12.2, SW5.2, U3.60 (BOOT0)
/D+: J1.A6 (D+), J1.B6 (D+), U2.6 (I/O1)
/D-: J1.A7 (D-), J1.B7 (D-), U2.4 (I/O2)
/NRST: C15.1, J2.12 (~RST), SW4.1, U3.7 (NRST)
/OSC_IN: C4.2, U3.5 (PH0), Y1.2
/OSC_OUT: R5.1, U3.6 (PH1)
/RFID_IRQ: J3.4, U3.26 (PB0)
/RFID_RST: J3.3, U3.24 (PC4)
/SPI1_MISO: J3.5, U3.22 (PA6)
/SPI1_MOSI: J3.2, U3.23 (PA7)
/SPI1_NSS: J3.7, U3.20 (PA4)
/SPI1_SCK: J3.6, U3.21 (PA5)
/SWCLK: J2.6 (JCLK/SWCLK), U3.49 (PA14)
/SWDIO: J2.4 (JTMS/SWDIO), U3.46 (PA13)
/SWO: J2.8 (JTDO/SWO), U3.55 (PB3)
/USBDM: U2.3 (I/O2), U3.44 (PA11)
/USBDP: U2.1 (I/O1), U3.45 (PA12)
/USR_BTN_1: C12.1, R8.1, U3.27 (PB1)
/USR_BTN_2: C13.1, R9.1, U3.28 (PB2)
/USR_LED_1: R6.1, U3.8 (PC0)
/USR_LED_2: R7.1, U3.9 (PC1)
/VCP_RX: J2.13 (VCP_RX), U3.43 (PA10)
/VCP_TX: J2.14 (VCP_TX), U3.42 (PA9)
GND: C1.2, C2.2, C3.1, C4.1, C5.2, C6.2, C7.2, C8.2, C9.2, C10.2, C11.1, C12.2, C13.2, C14.1, C15.2, C16.2, D1.1 (K), D2.1 (K), D3.1 (K), D4.1 (K), H1.1 (1_1), H2.1 (1_1), H3.1 (1_1), H4.1 (1_1), J1.A1 (GND), J1.A12 (GND), J1.B1 (GND), J1.B12 (GND), J1.S1 (SHIELD), J2.5 (GND), J2.7 (GND), J2.11 (GNDDetect), J3.1, R1.1, R2.2, R12.1, SW1.3 (C), SW2.2, SW3.2, SW4.2, U1.2 (GND), U2.2 (GND), U3.12 (VSSA), U3.18 (VSS), U3.31 (VSS), U3.47 (VSS), U3.63 (VSS)
unnamed: C6.1, R5.2, Y1.1
unnamed: D1.2 (A), R3.2
unnamed: D2.2 (A), R4.2
unnamed: D3.2 (A), R6.2
unnamed: D4.2 (A), R7.2
unnamed: J1.A5 (CC1), R1.2
unnamed: J1.B5 (CC2), R2.1
unnamed: R8.2, R10.1, SW2.1
unnamed: R9.2, R11.1, SW3.1
unnamed: SW1.2 (B), U1.3 (~SHDN)

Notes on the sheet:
STM32
Power supply
Mounting pad
SWD connector
Lecteur RFID HTRC
port USB

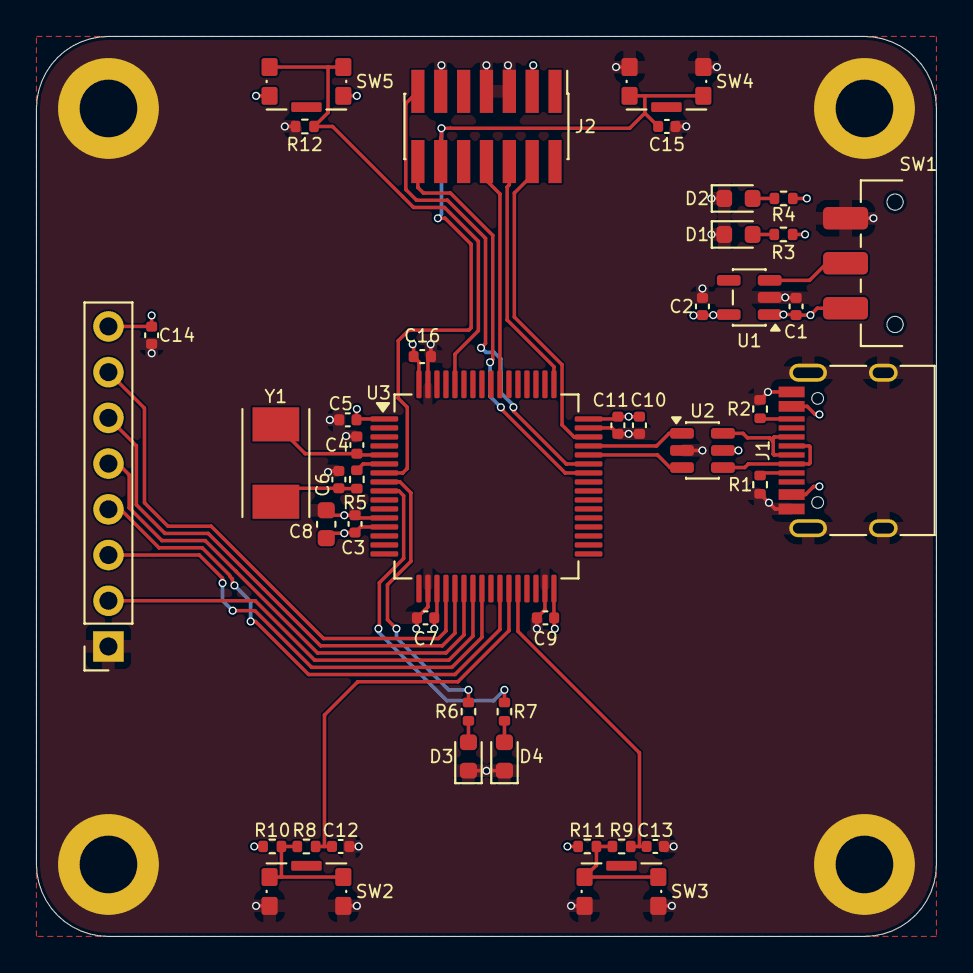
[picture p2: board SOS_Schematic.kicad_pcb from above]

Board: 4 copper layers, 50.0 x 50.0 mm, 48 parts (0 on the bottom side), 36 nets.

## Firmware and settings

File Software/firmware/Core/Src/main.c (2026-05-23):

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
/* Includes ------------------------------------------------------------------*/
#include "main.h"
#include "spi.h"
#include "usart.h"
#include "usb_otg.h"
#include "gpio.h"

/* USER CODE BEGIN Includes */
#include "rfid.h"
#include "algo.h"
/* USER CODE END Includes */


void SystemClock_Config(void);
/* USER CODE BEGIN 0 */
// pour les printf
int __io_putchar(int ch){
	HAL_UART_Transmit(&huart2, (uint8_t *)&ch, 1, HAL_MAX_DELAY);
	return ch;
}

int __io_getchar(void){
	uint8_t ch = 0;
	__HAL_UART_CLEAR_OREFLAG(&huart2);
	HAL_UART_Receive(&huart2, (uint8_t *)&ch, 1, HAL_MAX_DELAY);
	HAL_UART_Transmit(&huart2, (uint8_t *)&ch, 1, HAL_MAX_DELAY);
	return ch;
}
/* USER CODE END 0 */

/**
  * @brief  The application entry point.
  * @retval int
  */
int main(void)
{

  /* MCU Configuration--------------------------------------------------------*/

  /* Reset of all peripherals, Initializes the Flash interface and the Systick. */
  HAL_Init();

  /* Configure the system clock */
  SystemClock_Config();

  /* Initialize all configured peripherals */
  MX_GPIO_Init();
  MX_SPI1_Init();
  MX_USART1_UART_Init();
  MX_USB_OTG_FS_PCD_Init();
  MX_USART2_UART_Init();
  /* USER CODE BEGIN 2 */
	printf("Hello world Init\r\n");
	// INIT RFID
	RFID_init(&hrfid1, &hspi1, SPI1_NSS_GPIO_Port, SPI1_NSS_Pin, RFID_RST_GPIO_Port, RFID_RST_Pin);
  /* USER CODE END 2 */

  /* Infinite loop */
  /* USER CODE BEGIN WHILE */
	while (1)
	{
		printf("Hello world\r\n");
		HAL_Delay(1000);
		test();
    /* USER CODE END WHILE */

    /* USER CODE BEGIN 3 */
	}
  /* USER CODE END 3 */
}

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
/**
  * @brief  Period elapsed callback in non blocking mode
  * @note   This function is called  when TIM6 interrupt took place, inside
  * HAL_TIM_IRQHandler(). It makes a direct call to HAL_IncTick() to increment
  * a global variable "uwTick" used as application time base.
  * @param  htim : TIM handle
  * @retval None
  */
void HAL_TIM_PeriodElapsedCallback(TIM_HandleTypeDef *htim)
{
  if (htim->Instance == TIM6)
  {
    HAL_IncTick();
  }
}

/**
  * @brief  This function is executed in case of error occurrence.
  * @retval None
  */
void Error_Handler(void)
{
  /* USER CODE BEGIN Error_Handler_Debug */
	/* User can add his own implementation to report the HAL error return state */
	__disable_irq();
	while (1)
	{
	}
  /* USER CODE END Error_Handler_Debug */
}
#ifdef USE_FULL_ASSERT
/**
  * @brief  Reports the name of the source file and the source line number
  *         where the assert_param error has occurred.
  * @param  file: pointer to the source file name
  * @param  line: assert_param error line source number
  * @retval None
  */
void assert_failed(uint8_t *file, uint32_t line)
{
  /* USER CODE BEGIN 6 */
	/* User can add his own implementation to report the file name and line number,
     ex: printf("Wrong parameters value: file %s on line %d\r\n", file, line) */
  /* USER CODE END 6 */
}
#endif /* USE_FULL_ASSERT */

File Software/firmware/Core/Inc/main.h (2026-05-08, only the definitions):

#define USR_LED_1_Pin GPIO_PIN_0
#define USR_LED_1_GPIO_Port GPIOC
#define USR_LED_2_Pin GPIO_PIN_1
#define USR_LED_2_GPIO_Port GPIOC
#define SPI1_NSS_Pin GPIO_PIN_4
#define SPI1_NSS_GPIO_Port GPIOA
#define RFID_RST_Pin GPIO_PIN_4
#define RFID_RST_GPIO_Port GPIOC
#define RFID_IRQ_Pin GPIO_PIN_0
#define RFID_IRQ_GPIO_Port GPIOB
#define USR_BTN_1_Pin GPIO_PIN_1
#define USR_BTN_1_GPIO_Port GPIOB
#define USR_BTN_2_Pin GPIO_PIN_2
#define USR_BTN_2_GPIO_Port GPIOB

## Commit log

2026-02-05 Update and rename Exemple datasheet.txt to Dimensions des différentes boites
2026-02-05 Update and rename Dimensions des différentes boites to Dimensions des différentes boites.md
2026-02-17 work on HTRC and uC in schematic
    [SOS_Schematic.kicad_pcb, SOS_Schematic.kicad_sch]
2026-02-17 power supply schematic
    [SOS_Schematic.kicad_sch]
2026-02-19 schema pdf
    [SOS_Schematic.kicad_sch]
2026-02-19 Add URL for STM32L476RGT6 MCU
2026-02-19 schematic basics (usb and spec pins left)
    [SOS_Schematic.kicad_sch]
2026-02-19 updated schematic pdf
2026-02-19 Update Liste des composants: port USB
    [Liste des composants projets SOS - Feuille 1 (1).csv]
2026-02-19 schematic pre-final version
    [SOS_Schematic.kicad_sch]
2026-02-19 schematic post 1st revision (Vbat and SWD connector left)
    [SOS_Schematic.kicad_sch]
2026-02-19 final schematic
    [SOS_Schematic.kicad_sch]
2026-03-12 cleaning up & updating repository
    [SOS_Schematic.kicad_pcb, SOS_Schematic.kicad_sch]
2026-03-12 Update KiCAD Schematic: SWD
    [SOS_Schematic (4).kicad_pcb, SOS_Schematic (4).kicad_sch]
2026-03-18 Update schematic: RFID left
    [SOS_Schematic (4).kicad_sch]
2026-03-18 work on schematic and updating board
    [SOS_Schematic (4).kicad_pcb, SOS_Schematic (4).kicad_sch]
2026-03-19 update pin list and footprints
    [SOS_Schematic (4).kicad_sch, UJ20-C-R-G-TH-3-P14.step]
2026-03-19 schematic v2
    [SOS_Schematic (4).kicad_pcb, SOS_Schematic (4).kicad_sch, UJ20-C-R-G-TH-3-P14.step]
2026-03-19 Routage Board (sauf port USB)
    [SOS_Schematic (4).kicad_pcb, SOS_Schematic (4).kicad_sch]
2026-03-26 USB and board routing
    [SOS_Schematic (4).kicad_pcb, SOS_Schematic (4).kicad_sch]
2026-03-26 update schematic, create stm32cubeide project with pinout
    [SOS_Schematic (4).kicad_sch]
2026-03-27 Ajout code de Cube_Ide
2026-04-09 creating kicad board
    [SOS_Schematic (5).kicad_pcb]
2026-04-09 Update code
    [SOS_firmware.cfg]
2026-04-17 Update schematic avec les empreintes manquantes
    [SOS_Schematic (5).kicad_sch]
2026-04-17 Chanegement sur le PCB de routage
    [SOS_Schematic (5) (1).kicad_sch, SOS_Schematic (5).kicad_pcb, SOS_Schematic (5).kicad_sch]
2026-05-07 PCB final
    [SOS_Schematic (5).kicad_sch, SOS_Schematic final.kicad_pcb]
2026-05-07 dernière version
    [PCB_version_finale.kicad_pcb]
2026-05-07 code interface
    [2526_Stock_components.xlsx]
2026-05-07 PCB bonne version
    [SOS_Schematic (5).kicad_pcb]
2026-05-08 review pcb
    [SOS_Schematic (5).kicad_pcb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]
2026-05-11 cleaning git up
    [2526_Stock_components.xlsx, PCB_version_finale.kicad_pcb, SOS_Schematic (5) (1).kicad_sch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]
2026-05-23 clean gitup software
    [2526_Stock_components.xlsx]
2026-05-23 cleanup github hardware
    [PCB_version_finale.kicad_pcb, SOS_Schematic (5) (1).kicad_sch, SOS_Schematic (5).kicad_pcb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]

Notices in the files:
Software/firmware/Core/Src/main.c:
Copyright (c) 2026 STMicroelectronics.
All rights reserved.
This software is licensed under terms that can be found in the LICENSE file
